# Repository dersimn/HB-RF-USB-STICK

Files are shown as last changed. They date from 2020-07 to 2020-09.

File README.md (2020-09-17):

Smaller version of [HB-RF-USB](https://github.com/alexreinert/PCB). Electrically identical.  
Can be used to emulate a Homematic CCU with [RaspberryMatic](https://github.com/jens-maus/RaspberryMatic) in a virtual machine on x86 architecture.

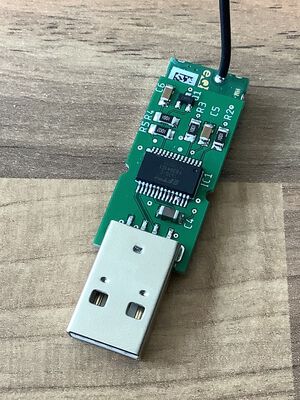
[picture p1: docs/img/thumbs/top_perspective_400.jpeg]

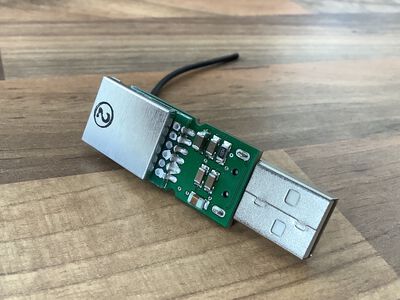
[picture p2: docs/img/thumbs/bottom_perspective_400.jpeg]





The HM-MOD-RPI-PCB kit comes with pre-soldered pins on the HM-MOD-UART-AW-SH-2. You have to desolder them first:

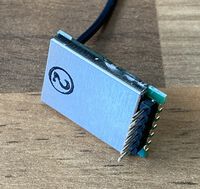
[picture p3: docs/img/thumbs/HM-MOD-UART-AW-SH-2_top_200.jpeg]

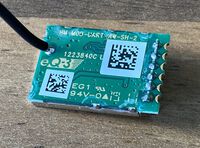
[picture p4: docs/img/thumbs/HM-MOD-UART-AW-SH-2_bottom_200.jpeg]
  
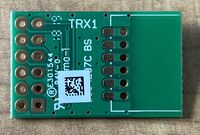
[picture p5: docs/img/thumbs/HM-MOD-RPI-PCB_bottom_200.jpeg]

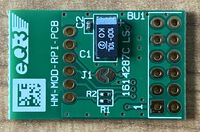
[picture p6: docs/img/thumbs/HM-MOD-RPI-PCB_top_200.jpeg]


## Required Parts

Shopping list with all used parts on [Reichelt](https://www.reichelt.de/my/1737625). You have to buy also one HM-MOD-RPI-PCB from ELV.

List:

- R (SMD 1206)
    - 1x 1 MΩ: [Reichelt](https://www.reichelt.de/smd-widerstand-1206-1-0-mohm-250-mw-1-rnd-1206-1-1m-p183429.html?&trstct=pol_0&nbc=1)
    - 1x 10 kΩ: [Reichelt](https://www.reichelt.de/smd-widerstand-1206-10-kohm-250-mw-1-rnd-1206-1-10k-p183394.html?&trstct=pol_0&nbc=1)
    - 3x 1 kΩ: [Reichelt](https://www.reichelt.de/smd-widerstand-1206-1-0-kohm-250-mw-1-rnd-1206-1-1-0k-p183379.html?&trstct=pol_2&nbc=1)
- C (SMD 1206)
    - 1x 100 µF: [Reichelt](https://www.reichelt.de/smd-vielschichtkondensator-g1206-100-f-6-3v-x5r-g1206-100-6-p89744.html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)
    - 1x 4.7 µF: [Reichelt](https://www.reichelt.de/smd-kerko-1206-4-7-f-50-v-10-mlcc-rnd-1501206b475k-p254230.html?&trstct=pol_0&nbc=1)
    - 3x 100 nF: [Reichelt](https://www.reichelt.de/vielschicht-kerko-100nf-50v-125-c-kem-x7r1206b100n-p207152.html?&nbc=1)
    - 1x 10 nF: [Reichelt](https://www.reichelt.de/vielschicht-kerko-10nf-50v-125-c-kem-x7r1206b10n-p207144.html?&trstct=pol_3&nbc=1)
    - 1x 4.7 nF: [Reichelt](https://www.reichelt.de/vielschicht-kerko-4-7nf-50v-125-c-kem-x7r1206-4-7n-p207141.html?&trstct=pol_5&nbc=1)
- L (SMD 1206)
    - ≥33 nH; ≤1 Ω (DC): [Reichelt](https://www.reichelt.de/smd-induktivitaet-1206-keramik-220n-l-1206as-220n-p72972.html?&trstct=pol_11&nbc=1)
- IC
    - 1x FT232RL: [Reichelt](https://www.reichelt.de/rs232-interface-bruecke-usb-zu-uart-ssop-28-ft-232-rl-p64399.html?&nbc=1)
    - 1x HM-MOD-UART-AW-SH-2 (included in HM-MOD-RPI-PCB): [ELV](https://de.elv.com/elv-homematic-komplettbausatz-funkmodul-fuer-raspberry-pi-hm-mod-rpi-pcb-fuer-smart-home-hausautomation-142141)
- Misc
    - 1x IRLML6402: [Reichelt](https://www.reichelt.de/mosfet-p-ch-20v-3-7a-1-3w-sot-23-irlml-6402-p108743.html?&nbc=1)
    - 1x A-USB A-LP-SMT-C: [Reichelt](https://www.reichelt.de/usb-einbaustecker-serie-a-gerade-180-vers-usb-agf-p52008.html?&nbc=1), [Conrad](https://www.conrad.de/de/p/usb-stecker-ultra-flach-stecker-einbau-a-usb-a-lp-smt-c-usb-a-smt-assmann-wsw-inhalt-1-st-741461.html)

## Order PCB

Use the provided Gerber files under Releases in the GitHub repository or generate your own CAM using Autodesk EAGLE.

I ordered the PCBs from [JLCPCB](https://jlcpcb.com). If you use their service you have to specify dimensions `33 x 16 mm` in the order mask and also add the Remark

> 2x Slotted Holes

## Flash FTDI

Get FT_Prog from [here](https://www.ftdichip.com/Support/Utilities.htm#FT_PROG). Use [`FT232R_Template.xml`](contrib/FT232R_Template.xml) for configuration:

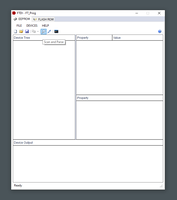
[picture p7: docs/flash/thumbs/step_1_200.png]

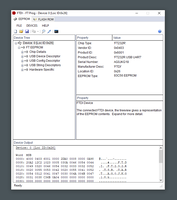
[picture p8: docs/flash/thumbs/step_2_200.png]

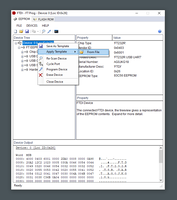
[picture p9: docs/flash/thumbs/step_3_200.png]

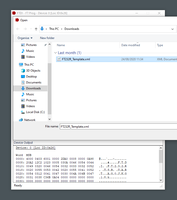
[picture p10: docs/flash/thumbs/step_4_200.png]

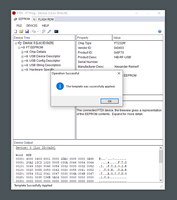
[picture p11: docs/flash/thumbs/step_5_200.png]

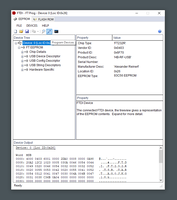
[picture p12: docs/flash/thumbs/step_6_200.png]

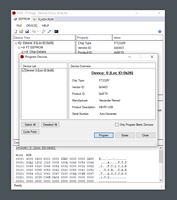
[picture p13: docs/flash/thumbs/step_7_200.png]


## Credits

- [@alexreinert/HB-RF-USB](https://github.com/alexreinert/PCB): Original idea.
- [@stan23/HB-MOD-UART-USB](https://github.com/stan23/myPCBs/tree/master/HB-MOD-UART-USB): Same goal as this project, but probably harder to solder due to 0603 SMD parts.

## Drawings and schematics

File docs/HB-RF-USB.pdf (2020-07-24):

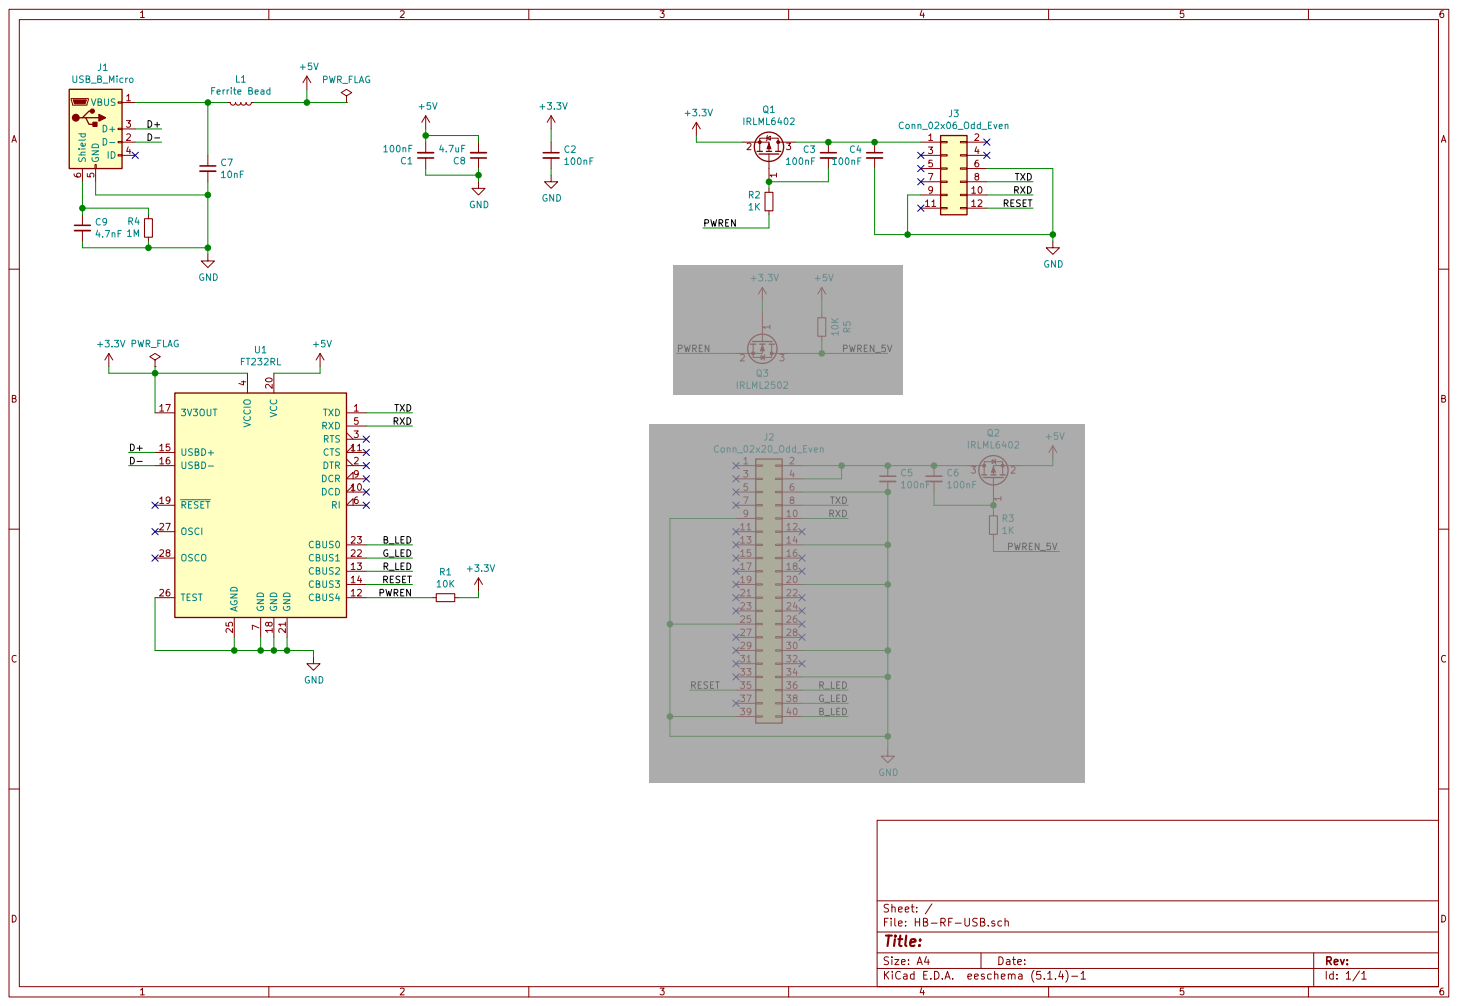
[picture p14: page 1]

Id: 1/1 Title: File: HB-RF-USB.sch Sheet: /

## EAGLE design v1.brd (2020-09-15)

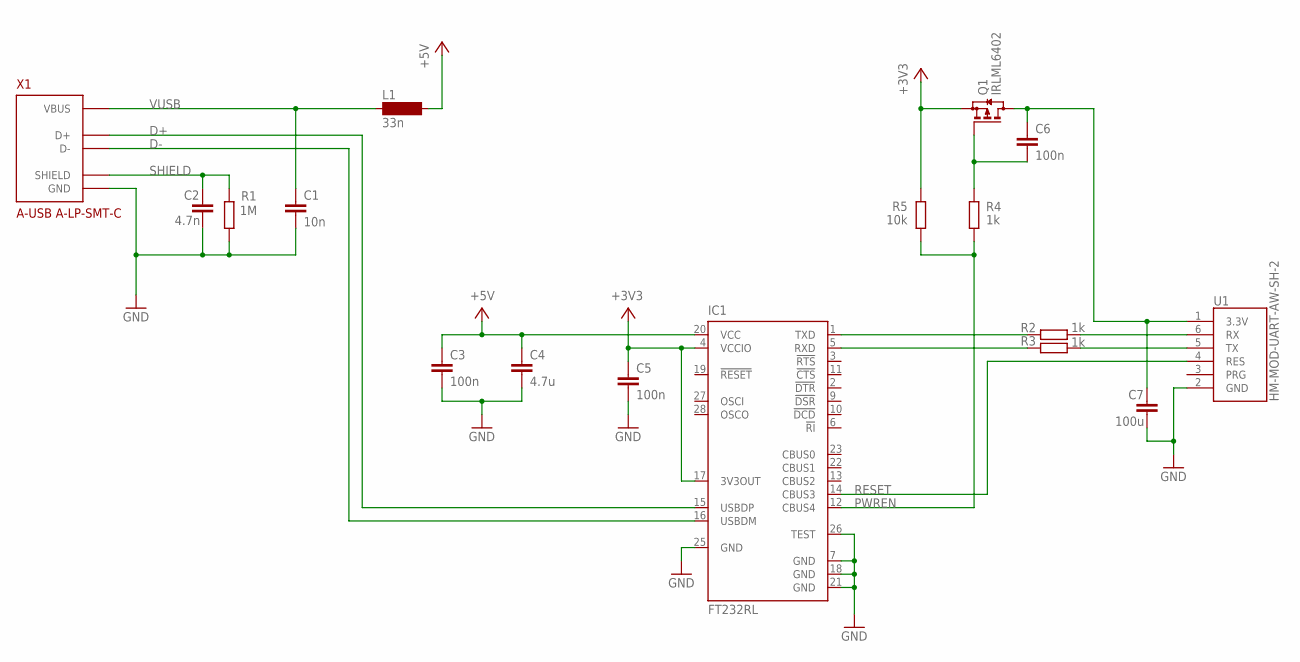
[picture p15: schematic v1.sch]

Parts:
C1: 10n; C1206
C2: 4.7n; C1206
C3, C5, C6: 100n; C1206
C4: 4.7u; C1206
C7: 100u; C1206
IC1: FT232RL; SSOP28
L1: 33n; SM-1206
Q1: IRLML6402; SOT23
R1: 1M; R1206
R2, R3, R4: 1k; R1206
R5: 10k; R1206
U1: HM-MOD-UART-AW-SH-2; HM-MOD-UART-AW-SH-2_SMD
X1: A-USB A-LP-SMT-C; A-USB_A-LP-SMT-C

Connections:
+3V3: C5.1, IC1.4 (VCCIO), IC1.17 (3V3OUT), Q1.2 (S), R5.2
+5V: C3.1, C4.1, IC1.20 (VCC), L1.2
D+: IC1.15 (USBDP), X1.3 (D+)
D-: IC1.16 (USBDM), X1.2 (D-)
GND: C1.2, C2.2, C3.2, C4.2, C5.2, C7.2, IC1.7 (GND), IC1.18 (GND), IC1.21 (GND), IC1.25 (GND), IC1.26 (TEST), R1.2, U1.2 (GND), X1.4 (GND)
unnamed: C6.1, C7.1, Q1.3 (D), U1.1 (3.3V)
unnamed: R2.2, U1.6 (RX)
unnamed: R3.2, U1.5 (TX)
unnamed: IC1.1 (TXD), R2.1
unnamed: IC1.5 (RXD), R3.1
unnamed: C6.2, Q1.1 (G), R4.2
PWREN: IC1.12 (CBUS4), R4.1, R5.1
RESET: IC1.14 (CBUS3), U1.4 (RES)
SHIELD: C2.1, R1.1, X1.S1 (SHIELD), X1.S2 (SHIELD)
VUSB: C1.1, L1.1, X1.1 (VBUS)

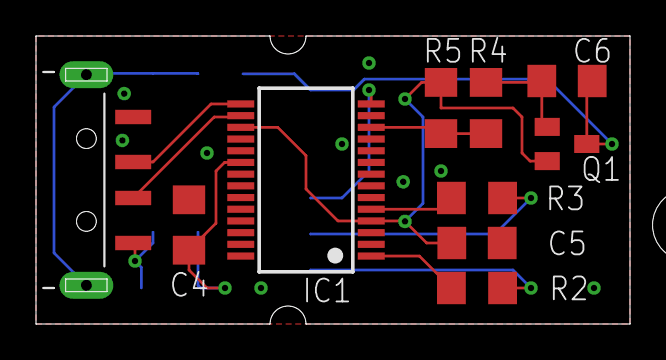
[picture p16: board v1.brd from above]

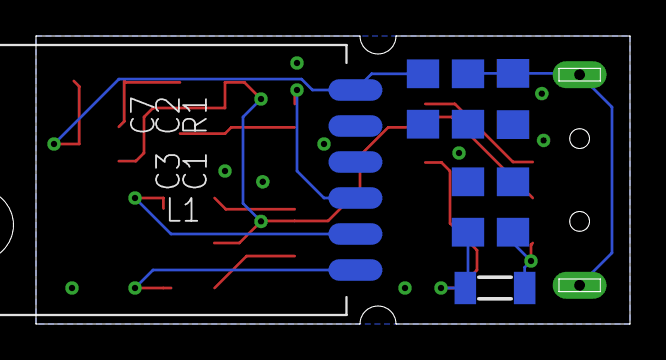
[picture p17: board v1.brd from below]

Board: 2 copper layers, 33.0 x 16.0 mm, 17 parts (7 on the bottom side), 15 nets.

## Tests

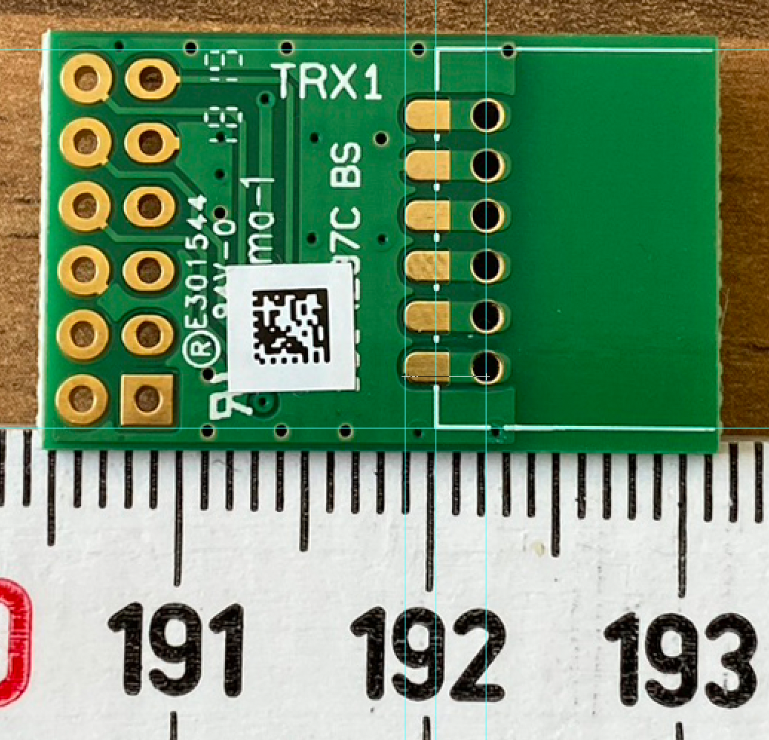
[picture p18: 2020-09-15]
docs/photoshop_measurements.png

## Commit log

2020-07-25 Default view
    [v1.brd]
2020-07-25 Cover vias with solder restist
    [v1.brd]
2020-09-15 Fix not connected pin TEST
    [v1.brd, v1.sch]

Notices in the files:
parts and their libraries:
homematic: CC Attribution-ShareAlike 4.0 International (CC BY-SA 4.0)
